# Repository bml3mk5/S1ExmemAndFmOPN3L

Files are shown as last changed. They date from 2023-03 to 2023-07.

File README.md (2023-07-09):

# Extended RAM & FM Synthesis Card for HITACHI MB-S1 (OPN3-L (YMF288) Version)

This is the extension card for HITACHI MB-S1 and Limelight. This is assembled two circuits
which are extended RAMs and FM Synthesis (YAMAHA YMF288(OPN3-L)). You can use two circuits, or just one of them.

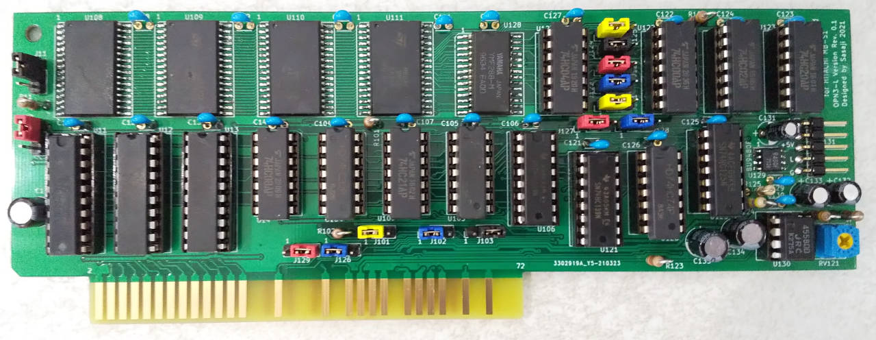
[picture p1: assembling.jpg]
Example of an assembling


## Used Tools

* KiCAD Version 5

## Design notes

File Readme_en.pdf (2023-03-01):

## Extended RAM & FM Synthesis Card for HITACHI MB-S1

## OPN3-L (YMF288) Version

Designed by Sasaji 2021 Rev. 0.1 This is the extension card for HITACHI MB-S1 and Limelight. This is assembled two circuits which are extended RAMs and FM Synthesis. You can use two circuits, or just one of them.

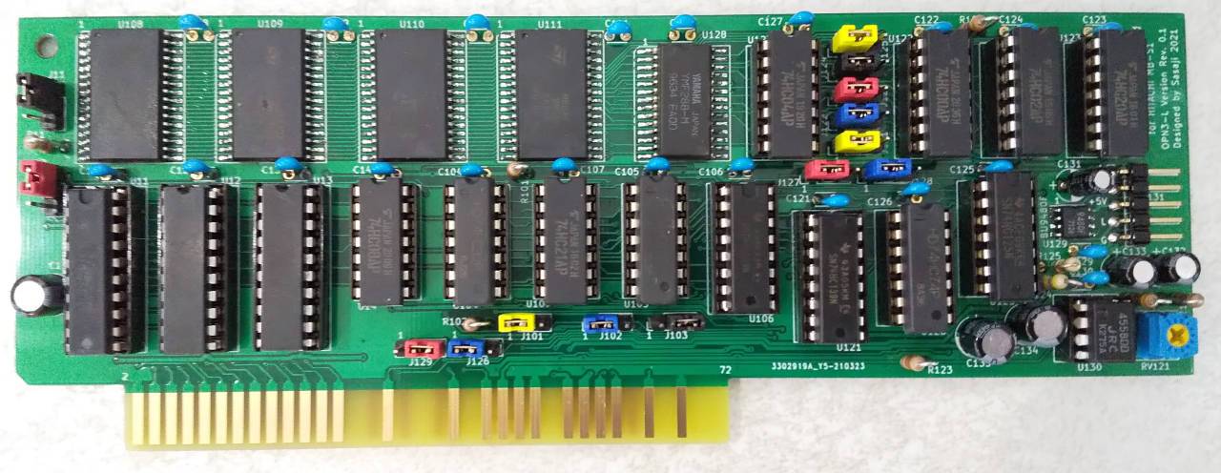
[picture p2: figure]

Example of assembling parts

## Parts List

- Parts number #1 to #99 are mandatory.
- Parts number #100 to #119 are necessary if you use extended RAMs.
- Parts number #120 to #139 are necessary if you use FM Synth.
Parts Number | Parts Name | Qty. | Description
C1 | Electrolytic Capacitor | 1 | 47～100uF, 16V～
C11~C130 | Ceramic Capacitor | 22 | 0.1uF
C131 | Electrolytic Capacitor | 1 | 10uF, 16V～
C132,C133 | Electrolytic Capacitor | 2 | 22uF～47uF, 16V～
C134,C135 | Electrolytic Capacitor | 2 | 47uF～100uF, 25V～
R11~R102, R126 | Carbon Resistor | 6 | 4.7KΩ～10KΩ, 1/4W～ (Pullup Register)
R121,R122 | Carbon Resistor | 2 | 4.7KΩ, 1/4W～
R123 | Carbon Resistor | 1 | 1KΩ, 1/4W～
R124 | Carbon Resistor | 1 | 100KΩ～470KΩ, 1/4W～ (For Opamp. Register value is 10 * R125)
R125 | Carbon Resistor | 1 | 10KΩ～47KΩ, 1/4W～ (For Opamp. Register value is R124 / 10)

RV121 | Potentiometer | 1 | 10KΩ Ex: Tokyo Cosmos GF063P1B103 (Volume sound)
U11 | CMOS Logic IC | 1 | 74HC245, DIP20
U12, U13 | CMOS Logic IC | 2 | 74HC541, DIP20
U14 | CMOS Logic IC | 1 | 74HC08, DIP14
U104 | CMOS Logic IC | 1 | 74HC32, DIP14
U105,U122 | CMOS Logic IC | 2 | 74HC00, DIP14
U106,U121 | CMOS Logic IC | 2 | 74HC139, DIP16
U107 | CMOS Logic IC | 1 | 74HC21, DIP14
U108~U111 | SRAM | 4 | M68AF127B or Compatible SRAM, SOIC32
U123 | CMOS Logic IC | 1 | 74HC20, DIP14
U124 | CMOS Logic IC | 1 | 74HC02, DIP14
U125 | CMOS Logic IC | 1 | 74HC125, DIP14
U126 | CMOS Logic IC | 1 | 74HC74, DIP14
U127 | CMOS Logic IC | 1 | 74HC04, DIP14
U128 | FMSynth IC | 1 | YMF288-M, SOIC28
U129 | DAC | 1 | BU9480F, SOP8 (16bit DAC, I²S)
U129 | Opamp | 1 | 4580 or 4558 ±12V, DIP8 (NJM4580D, RC4580)
J11~J129 | Jumper | 14 | Pin Header 3pin x1 2.54mm pitch straight
| Jumper Pin | 14 | To short pin headers.
| IC Socket

Optional Parts
Parts Number | Parts Name | Qty. | Description
J131 | Jumper | 1 | Pin Header 5pin x1 2.54mm pitch L.angled (For output sound)

## About Output Sound Signals Pin

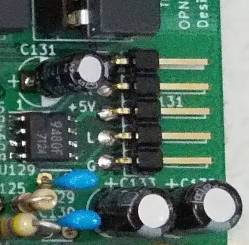
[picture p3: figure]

Pins are GND, Right OUT, +5V, Left OUT and GND from the top side. Sound is a direct signal from the DAC. If you use this signal, you must amplify it using an opamp.

## Setting Jumper

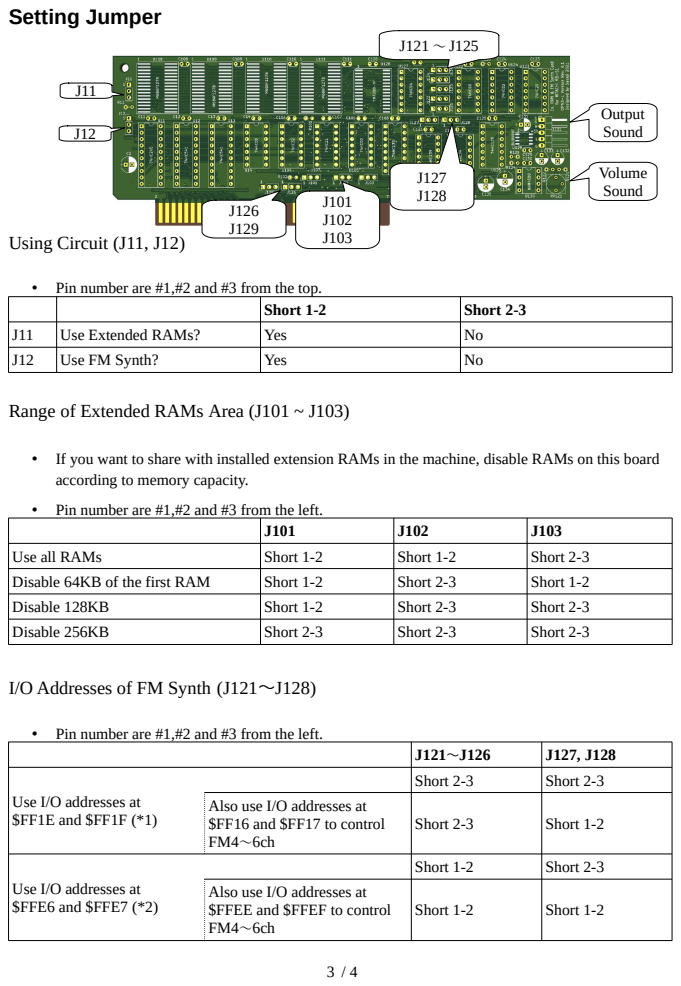
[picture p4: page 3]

• Pin number are #1,#2 and #3 from the top.

Short 1-2 | Short 2-3

J11 | Use Extended RAMs? | Yes | No
J12 | Use FM Synth? | Yes | No

Range of Extended RAMs Area (J101 ~ J103)

• If you want to share with installed extension RAMs in the machine, disable RAMs on this board
according to memory capacity.
• Pin number are #1,#2 and #3 from the left.

Use all RAMs | Short 1-2 | Short 1-2 | Short 2-3
Disable 64KB of the first RAM | Short 1-2 | Short 2-3 | Short 1-2
Disable 128KB | Short 1-2 | Short 2-3 | Short 2-3
Disable 256KB | Short 2-3 | Short 2-3 | Short 2-3

I/O Addresses of FM Synth (J121～J128)

Use I/O addresses at Also use I/O addresses at $FF1E and $FF1F (*1) $FF16 and $FF17 to control FM4～6ch | Short 2-3 | Short 2-3 Short 1-2

Use I/O addresses at Also use I/O addresses at $FFE6 and $FFE7 (*2) $FFEE and $FFEF to control FM4～6ch | Short 1-2 | Short 2-3 Short 1-2

(*1) Don’t use on B mode of MB-S1/30 and 40 because duplicate the FD interface. (*2) Select this if you use as Extended PSG.

Connecting Interrupt Signal of FM Synth (J129)

- Pin number are #1,#2 and #3 from the left.
| | Short 1-2 | Short 2-3
J129 | Connect to | IRQ | FIRQ

## Attention

- The jumpers J127 and J128 must be at the same shorting position.
- This board is a prototype. No consideration is given to noise generated during use and deterioration over time.

## Difference from OPN(YM2203)

- Added channel 4 to 6 of FM synth. Enable I/O addresses to use it (see Setting Jumper).
- Prescaler is constant (as FM:1/3, SSG:1/2 on OPN). This raises a pitch in the PLAY statement by one octave.
- The FM and SSG outputs are combined. It's not possible to adjust the volumes of each one individually.

## Disclaimer

I am not responsible for any damage caused by this board. You use this board at your own risk.

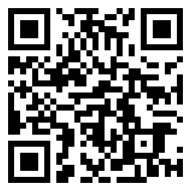
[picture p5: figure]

## Web

There are this document and a CAD data on the web. http://s-sasaji.ddo.jp/bml3mk5/s1exmemfm.htm
QR code →

Sasaji (sasaji@s-sasaji.ddo.jp) http://s-sasaji.ddo.jp/bml3mk5/(Twitter: https://twitter.com/bml3mk5)

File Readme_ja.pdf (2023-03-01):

# 拡張 RAM & FM 音源カード for 日立 MB-S1

# OPN3-L (YMF288) Version

### Designed by Sasaji 2021 Rev. 0.1

日立 MB-S1 および来夢来人用の拡張カードです。拡張 RAM の回路と FM 音源の回路を実装しています。 どちらか一方を使用するようにもできます。


実装例

## 部品表

- 1～99 番台の部品は必須です。
- 拡張 RAM を使用する場合、100～119 番台の部品が必要です。
- FM 音源を使用する場合、120～139 番台の部品が必要です。
番号 | 部品名 | 数量 | 値など
C1 | 電解コンデンサ | 1 | 47～100uF, 16V～
C11~C130 | セラミックコンデンサ | 22 | 0.1uF
C131 | 電解コンデンサ | 1 | 10uF, 16V～
C132,C133 | 電解コンデンサ | 2 | 22uF～47uF, 16V～
C134,C135 | 電解コンデンサ | 2 | 47uF～100uF, 25V～
R11~R102, R126 | カーボン抵抗 | 6 | 4.7KΩ～10KΩ, 1/4W～ （プルアップ抵抗）
R121,R122 | カーボン抵抗 | 2 | 4.7KΩ, 1/4W～
R123 | カーボン抵抗 | 1 | 1KΩ, 1/4W～
R124 | カーボン抵抗 | 1 | 100KΩ～470KΩ, 1/4W～ （オペアンプ用、抵抗値は R125 の 10 倍）
R125 | カーボン抵抗 | 1 | 10KΩ～47KΩ, 1/4W～ （オペアンプ用、抵抗値は R124 の 1/10）

RV121 | 半固定抵抗(ポテンショ メータ) | 1 | 10KΩ 東京コスモス電機 GF063P1B103 など （音量調整用）
U11 | CMOS ロジック IC | 1 | 74HC245, DIP20 ピン
U12, U13 | CMOS ロジック IC | 2 | 74HC541, DIP20 ピン
U14 | CMOS ロジック IC | 1 | 74HC08, DIP14 ピン
U104 | CMOS ロジック IC | 1 | 74HC32, DIP14 ピン
U105,U122 | CMOS ロジック IC | 2 | 74HC00, DIP14 ピン
U106,U121 | CMOS ロジック IC | 2 | 74HC139, DIP16 ピン
U107 | CMOS ロジック IC | 1 | 74HC21, DIP14 ピン
U108~U111 | SRAM | 4 | M68AF127B または互換 SRAM, SOIC32 ピン
U123 | CMOS ロジック IC | 1 | 74HC20, DIP14 ピン
U124 | CMOS ロジック IC | 1 | 74HC02, DIP14 ピン
U125 | CMOS ロジック IC | 1 | 74HC125, DIP14 ピン
U126 | CMOS ロジック IC | 1 | 74HC74, DIP14 ピン
U127 | CMOS ロジック IC | 1 | 74HC04, DIP14 ピン
U128 | FM 音源 IC | 1 | YMF288-M, SOIC28 ピン
U129 | DAC | 1 | BU9480F, SOP8 ピン （16 ビット DAC, I²S 入力のもの）
U129 | オペアンプ | 1 | 4580 や 4558 など±12V 以上のもの, DIP8 ピン （NJM4580D, RC4580 など）
J11~J129 | ジャンパ | 14 | ピンヘッダ 3 ピン x1 列 2.54mm ピッチ ストレート
| ジャンパピン | 14 | 上記ピンヘッダをショートさせるため
| IC ソケット

以下の部品はオプション

番号 | 部品名 | 数量 | 値など
J131 | ジャンパ | 1 | ピンヘッダ 5 ピン x1 列 2.54mm ピッチ L アングル （音声出力用）

## 音声出力端子について


### 上から、GND, Right OUT, +5V, Left OUT, GND となります。

音声は DAC からでた直後の信号です。ここから音声を取り出す場合は、オペア ンプなどで増幅してください。

## ジャンパピンの設定

J11

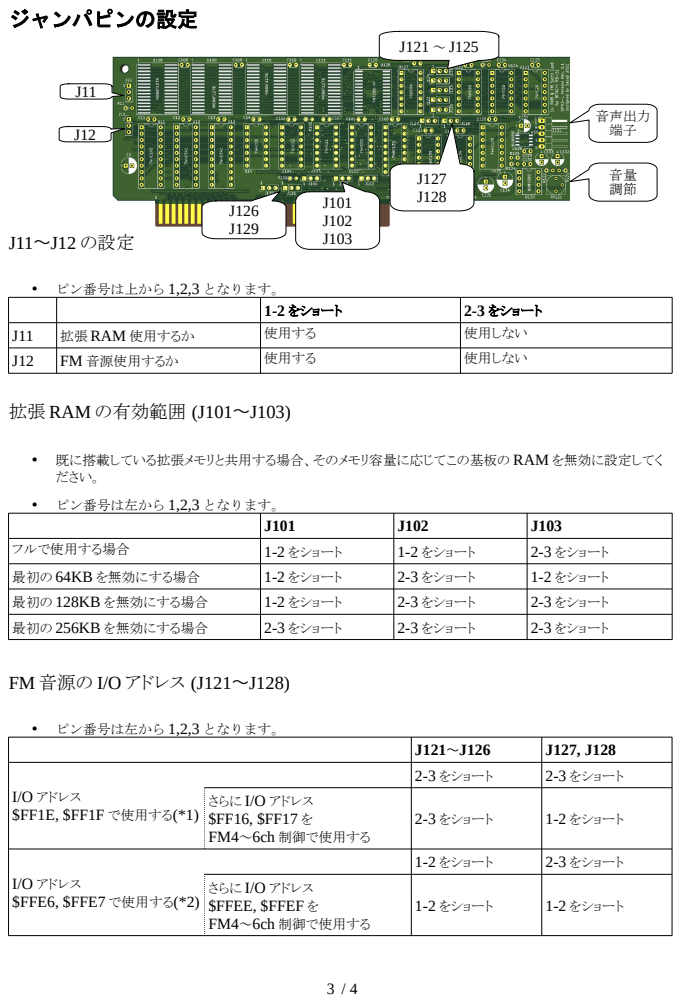
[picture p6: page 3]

1-2 をショート | 2-3 をショート

J11 | 拡張 RAM 使用するか | 使用する | 使用しない
J12 | FM 音源使用するか | 使用する | 使用しない

• 既に搭載している拡張メモリと共用する場合、そのメモリ容量に応じてこの基板の RAM を無効に設定してく
ださい。
• ピン番号は左から 1,2,3 となります。

フルで使用する場合 | 1-2 をショート | 1-2 をショート | 2-3 をショート
最初の 64KB を無効にする場合 | 1-2 をショート | 2-3 をショート | 1-2 をショート
最初の 128KB を無効にする場合 | 1-2 をショート | 2-3 をショート | 2-3 をショート
最初の 256KB を無効にする場合 | 2-3 をショート | 2-3 をショート | 2-3 をショート

I/O アドレス さらに I/O アドレス $FF1E, $FF1F で使用する(*1) $FF16, $FF17 を FM4～6ch 制御で使用する | 2-3 をショート | 2-3 をショート 1-2 をショート

I/O アドレス さらに I/O アドレス $FFE6, $FFE7 で使用する(*2) $FFEE, $FFEF を FM4～6ch 制御で使用する | 1-2 をショート | 2-3 をショート 1-2 をショート

(*1)FD インターフェースと重複するため、MB-S1/30,40 の B モードでは使用しないでください。 (*2)拡張 PSG として使用する場合はこちらを選択してください。

## FM 音源の割り込み信号接続先(J129)

- ピン番号は左から 1,2,3 となります。
| | 1-2 をショート | 2-3 をショート
J129 | 割り込み信号接続先 | IRQ | FIRQ

## 使用上の注意

- ジャンパ J127,J128 はショートする位置を合わせてください。
- この基板は試作品です。使用中に発生するノイズや経年劣化などに対しての考慮は全くしていません ので予めご了承ください。

# OPN(YM2203)との違い

- FM 音源部のチャンネル 4 から 6 が追加されました。これを使用するには FM4～6ch 制御で使用する I/O アドレスを有効にしてください(ジャンパピンの設定を参照)。
- 分周比が固定(OPN の設定 FM:1/3 SSG:1/2 に相当)になりました。このため PLAY 文での音程が 1 オクターブ上がります。
- FM 音源部と SSG 部が合成して出力されるようになりました。FM 音源と SSG 個別に音量を調整す ることはできません。

## 免責事項

この基板によって発生したいかなる損害についても当方は一切責任を負いません。 この基板を使用するにあたってはすべて自己責任で行ってください。


# Web ページ

この資料や CAD データなどを置いています。

### http://s-sasaji.ddo.jp/bml3mk5/s1exmemfm.htm

QR コード→

連絡先：

### Sasaji (sasaji@s-sasaji.ddo.jp) http://s-sasaji.ddo.jp/bml3mk5/ (Twitter: https://twitter.com/bml3mk5)

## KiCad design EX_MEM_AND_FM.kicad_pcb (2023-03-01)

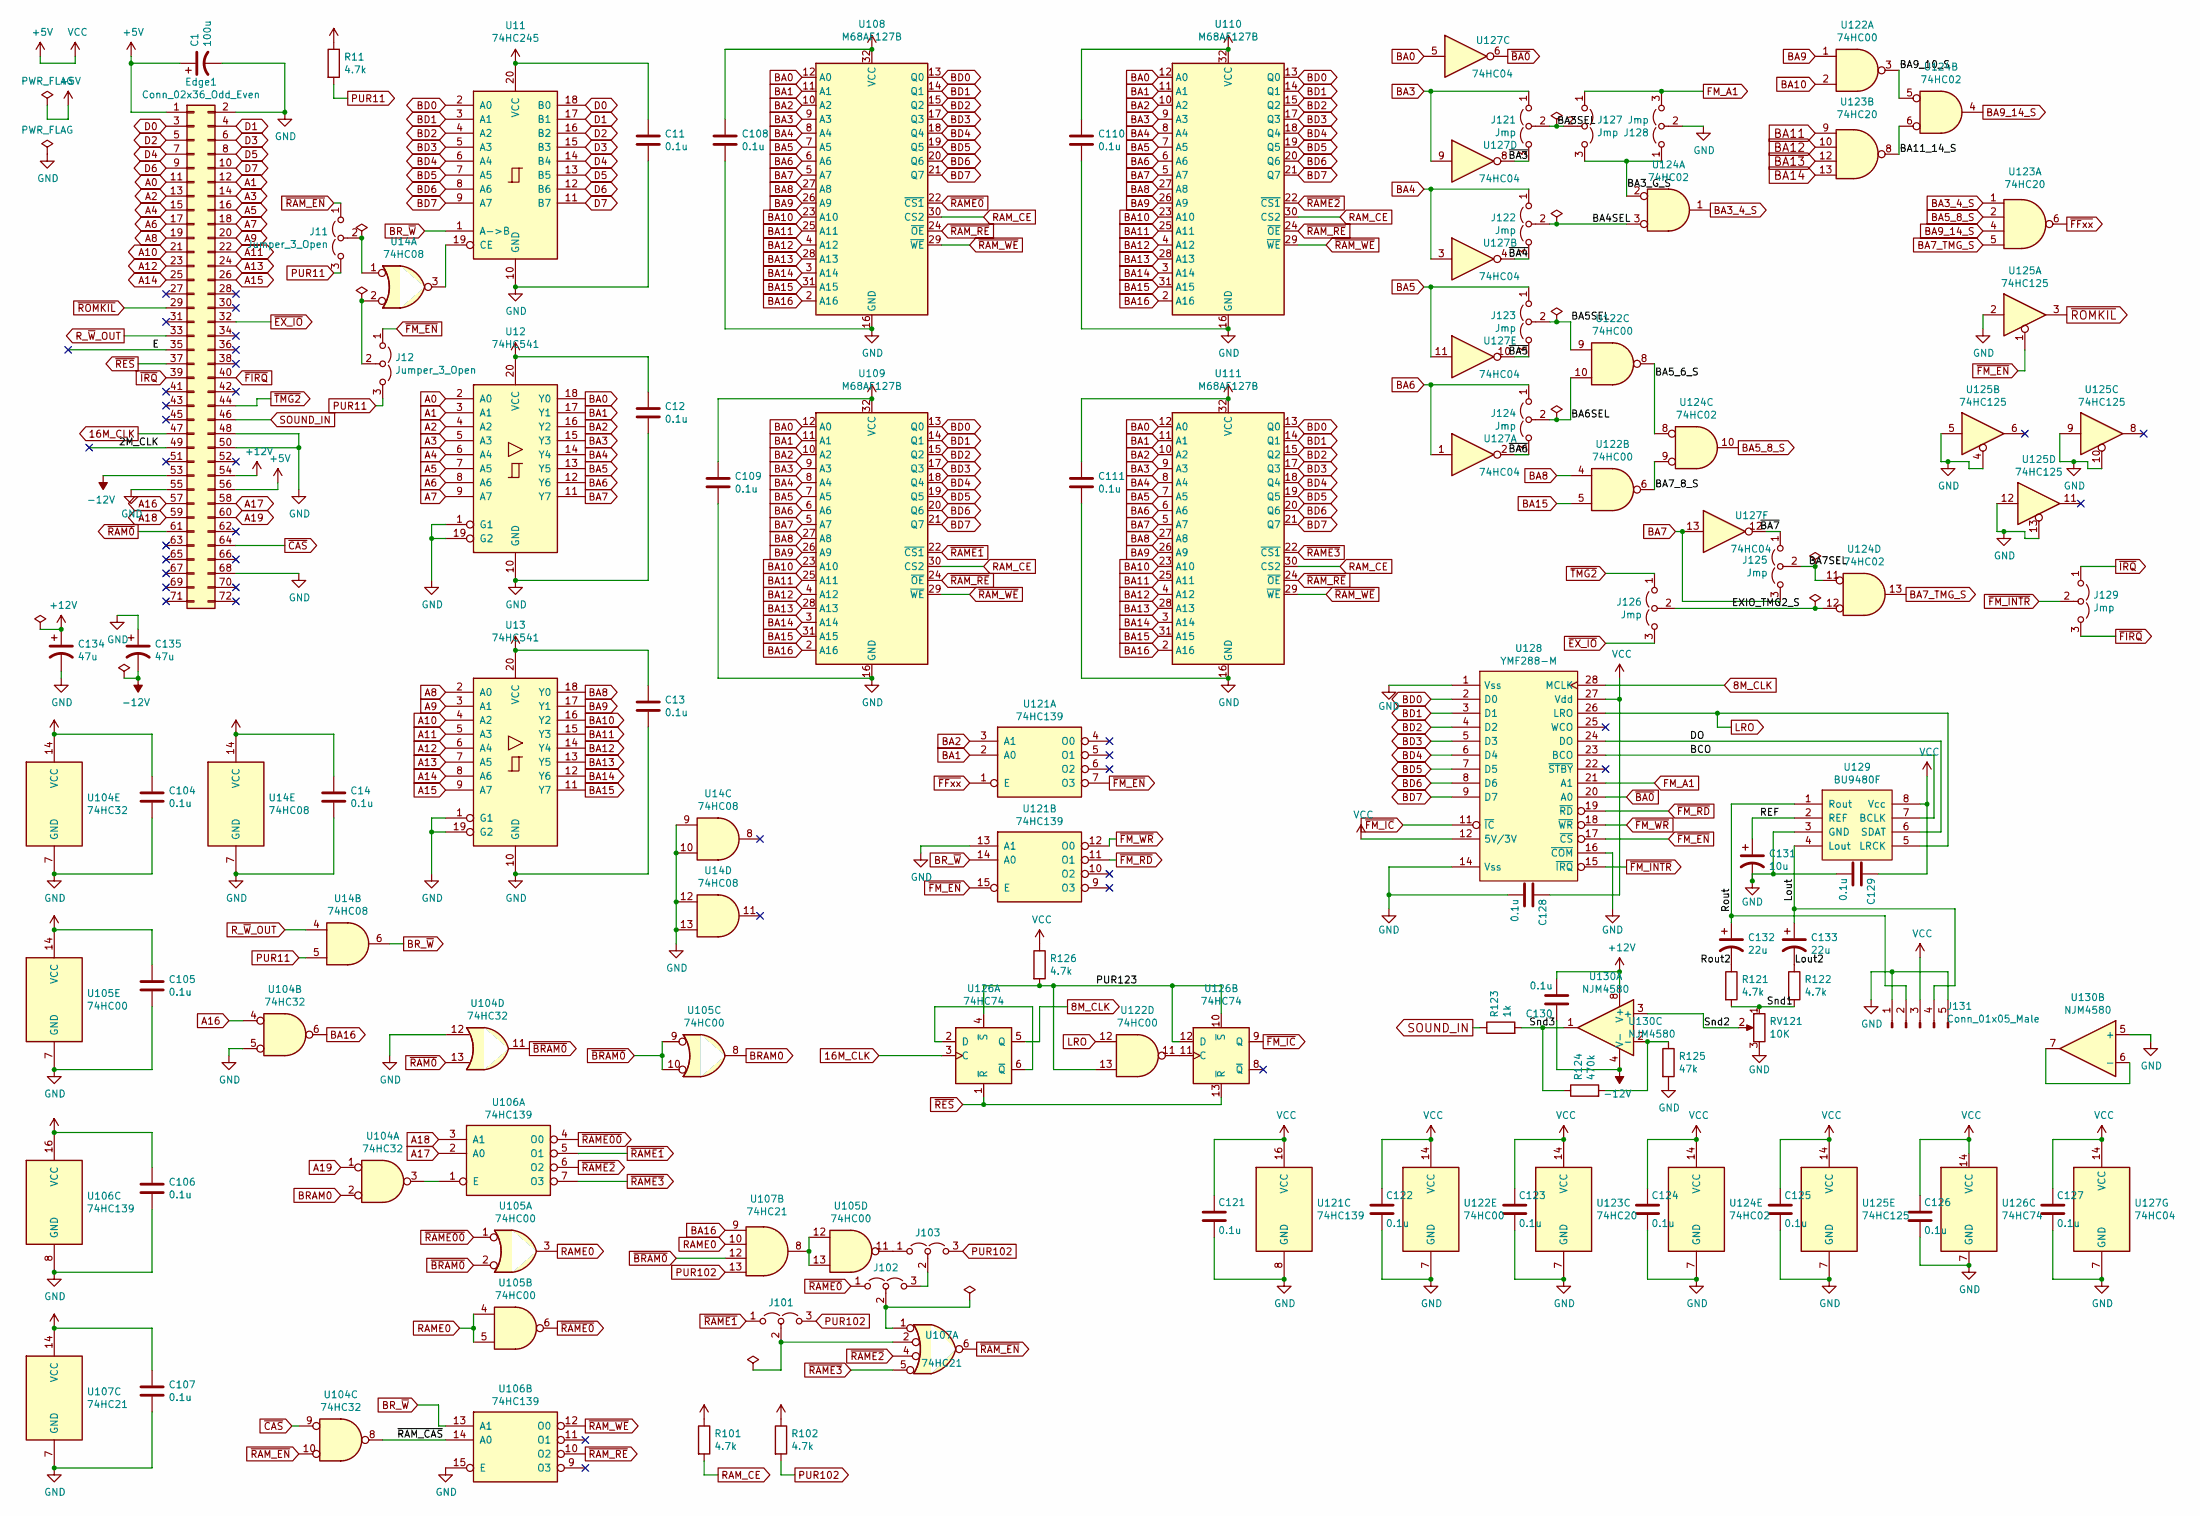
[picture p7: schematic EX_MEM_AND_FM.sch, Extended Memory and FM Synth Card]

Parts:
C1: 100u; CP_Radial_D6.3mm_P2.50mm
C11, C12, C13, C14, C104, C105, C106, C107, C108, C109, C110, C111, C121, C122, C123, C124, C125, C126, C127, C128, C129, C130: 0.1u; C_Disc_D3.0mm_W2.0mm_P2.50mm
C131: 10u; CP_Radial_D5.0mm_P2.50mm
C132, C133: 22u; CP_Radial_D5.0mm_P2.50mm
C134, C135: 47u; CP_Radial_D6.3mm_P2.50mm
Edge1: Conn_02x36_Odd_Even; CardEdge72
J11, J12, J101, J102, J103: Jumper_3_Open; Pin_Header_Straight_1x03_Pitch2.54mm
J121, J122, J123, J124, J125, J126, J127, J128, J129: Jmp; Pin_Header_Straight_1x03_Pitch2.54mm
J131: Conn_01x05_Male; Pin_Header_Angled_1x05_Pitch2.54mm
R11, R101, R102, R121, R122, R126: 4.7k; R_Axial_DIN0204_L3.6mm_D1.6mm_P2.54mm_Vertical
R123: 1k; R_Axial_DIN0204_L3.6mm_D1.6mm_P2.54mm_Vertical
R124: 470k; R_Axial_DIN0204_L3.6mm_D1.6mm_P2.54mm_Vertical
R125: 47k; R_Axial_DIN0204_L3.6mm_D1.6mm_P2.54mm_Vertical
RV121: 10K; Potentiometer_Trimmer_Bourns_3339P_Horizontal
U11: 74HC245; DIP-20_W7.62mm
U12, U13: 74HC541; DIP-20_W7.62mm
U14: 74HC08; DIP-14_W7.62mm
U104: 74HC32; DIP-14_W7.62mm
U105: 74HC00; DIP-14_W7.62mm
U106: 74HC139; DIP-16_W7.62mm
U107: 74HC21; DIP-14_W7.62mm
U108, U109, U110, U111: M68AF127B; SOIC-32
U121: 74HC139; DIP-16_W7.62mm_Socket
U122: 74HC00; DIP-14_W7.62mm_Socket
U123: 74HC20; DIP-14_W7.62mm_Socket
U124: 74HC02; DIP-14_W7.62mm_Socket
U125: 74HC125; DIP-14_W7.62mm_Socket
U126: 74HC74; DIP-14_W7.62mm_Socket
U127: 74HC04; DIP-14_W7.62mm
U128: YMF288-M; SOIC-28
U129: BU9480F; SOIC-8_3.9x4.9mm_Pitch1.27mm
U130: NJM4580; DIP-8_W7.62mm_Socket

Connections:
8M_CLK: U126.5 (Q), U128.28 (MCLK)
16M_CLK: Edge1.47, U126.3 (C)
+5V: C1.1, C11.1, C12.1, C13.1, C14.1, C104.1, C105.1, C106.1, C107.1, C108.1, C109.1, C110.1, C111.1, C121.1, C122.1, C123.1, C124.1, C125.1, C126.1, C127.1, C128.1, C129.1, Edge1.1, Edge1.56, J131.3, R11.1, R101.1, R102.1, R126.1, U11.20 (VCC), U12.20 (VCC), U13.20 (VCC), U14.14 (VCC), U104.14 (VCC), U105.14 (VCC), U106.16 (VCC), U107.14 (VCC), U108.32 (VCC), U109.32 (VCC), U110.32 (VCC), U111.32 (VCC), U121.16 (VCC), U122.14 (VCC), U123.14 (VCC), U124.14 (VCC), U125.14 (VCC), U126.14 (VCC), U127.14 (VCC), U128.12 (5V/3V), U128.27 (Vdd), U129.8 (Vcc)
+12V: C130.2, C134.1, Edge1.54, U130.8 (V+)
-12V: C130.1, C135.2, Edge1.53, U130.4 (V-)
/BA3SEL: J121.2 (C), J127.2 (C)
/BA3_G_S: J127.3 (B), J128.1 (A), U124.2
/BA4SEL: J122.2 (C), U124.3
/BA5SEL: J123.2 (C), U122.9
/BA5_6_S: U122.8, U124.8
/BA6SEL: J124.2 (C), U122.10
/BA7SEL: J125.2 (C), U124.11
/BA7_8_S: U122.6, U124.9
/BA9_10_S: U122.3, U124.5
/BA11_14_S: U123.8, U124.6
/BCO: U128.23 (BCO), U129.7 (BCLK)
/DO: U128.24 (DO), U129.6 (SDAT)
/EXIO_TMG2_S: J126.2 (C), U124.12
/Lout: C133.1, J131.4, U129.4 (Lout)
/Lout2: C133.2, R122.1
/PUR123: R126.2, U122.13, U126.4 (~S), U126.10 (~S), U126.12 (D)
/REF: C131.1, U129.2 (REF)
/Rout: C132.1, J131.2, U129.1 (Rout)
/Rout2: C132.2, R121.1
/Snd1: R121.2, R122.2, RV121.1
/Snd2: RV121.2, U130.3 (+)
/Snd3: R123.2, R124.1, U130.1
/~BA3: J121.3 (B), U127.8
/~BA4: J122.3 (B), U127.4
/~BA5: J123.3 (B), U127.10
/~BA6: J124.3 (B), U127.2
/~BA7: J125.1 (A), U127.12
/~RAM_CAS: U104.8, U106.14 (A0)
A0: Edge1.11, U12.2 (A0)
A1: Edge1.12, U12.3 (A1)
A2: Edge1.13, U12.4 (A2)
A3: Edge1.14, U12.5 (A3)
A4: Edge1.15, U12.6 (A4)
A5: Edge1.16, U12.7 (A5)
A6: Edge1.17, U12.8 (A6)
A7: Edge1.18, U12.9 (A7)
A8: Edge1.19, U13.2 (A0)
A9: Edge1.20, U13.3 (A1)
A10: Edge1.21, U13.4 (A2)
A11: Edge1.22, U13.5 (A3)
A12: Edge1.23, U13.6 (A4)
A13: Edge1.24, U13.7 (A5)
A14: Edge1.25, U13.8 (A6)
A15: Edge1.26, U13.9 (A7)
A16: Edge1.57, U104.4
A17: Edge1.58, U106.2 (A0)
A18: Edge1.59, U106.3 (A1)
A19: Edge1.60, U104.1
BA0: U12.18 (Y0), U108.12 (A0), U109.12 (A0), U110.12 (A0), U111.12 (A0), U127.5
BA1: U12.17 (Y1), U108.11 (A1), U109.11 (A1), U110.11 (A1), U111.11 (A1), U121.2 (A0)
BA2: U12.16 (Y2), U108.10 (A2), U109.10 (A2), U110.10 (A2), U111.10 (A2), U121.3 (A1)
BA3: J121.1 (A), U12.15 (Y3), U108.9 (A3), U109.9 (A3), U110.9 (A3), U111.9 (A3), U127.9
BA3_4_S: U123.1, U124.1
BA4: J122.1 (A), U12.14 (Y4), U108.8 (A4), U109.8 (A4), U110.8 (A4), U111.8 (A4), U127.3
BA5: J123.1 (A), U12.13 (Y5), U108.7 (A5), U109.7 (A5), U110.7 (A5), U111.7 (A5), U127.11
BA5_8_S: U123.2, U124.10
BA6: J124.1 (A), U12.12 (Y6), U108.6 (A6), U109.6 (A6), U110.6 (A6), U111.6 (A6), U127.1
BA7: J125.3 (B), U12.11 (Y7), U108.5 (A7), U109.5 (A7), U110.5 (A7), U111.5 (A7), U127.13
BA7_TMG_S: U123.5, U124.13
BA8: U13.18 (Y0), U108.27 (A8), U109.27 (A8), U110.27 (A8), U111.27 (A8), U122.4
BA9: U13.17 (Y1), U108.26 (A9), U109.26 (A9), U110.26 (A9), U111.26 (A9), U122.1
BA9_14_S: U123.4, U124.4
BA10: U13.16 (Y2), U108.23 (A10), U109.23 (A10), U110.23 (A10), U111.23 (A10), U122.2
BA11: U13.15 (Y3), U108.25 (A11), U109.25 (A11), U110.25 (A11), U111.25 (A11), U123.9
BA12: U13.14 (Y4), U108.4 (A12), U109.4 (A12), U110.4 (A12), U111.4 (A12), U123.10
BA13: U13.13 (Y5), U108.28 (A13), U109.28 (A13), U110.28 (A13), U111.28 (A13), U123.12
BA14: U13.12 (Y6), U108.3 (A14), U109.3 (A14), U110.3 (A14), U111.3 (A14), U123.13
BA15: U13.11 (Y7), U108.31 (A15), U109.31 (A15), U110.31 (A15), U111.31 (A15), U122.5
BA16: U104.6, U107.9, U108.2 (A16), U109.2 (A16), U110.2 (A16), U111.2 (A16)
BD0: U11.2 (A0), U108.13 (Q0), U109.13 (Q0), U110.13 (Q0), U111.13 (Q0), U128.2 (D0)
BD1: U11.3 (A1), U108.14 (Q1), U109.14 (Q1), U110.14 (Q1), U111.14 (Q1), U128.3 (D1)
BD2: U11.4 (A2), U108.15 (Q2), U109.15 (Q2), U110.15 (Q2), U111.15 (Q2), U128.4 (D2)
BD3: U11.5 (A3), U108.17 (Q3), U109.17 (Q3), U110.17 (Q3), U111.17 (Q3), U128.5 (D3)
BD4: U11.6 (A4), U108.18 (Q4), U109.18 (Q4), U110.18 (Q4), U111.18 (Q4), U128.6 (D4)
BD5: U11.7 (A5), U108.19 (Q5), U109.19 (Q5), U110.19 (Q5), U111.19 (Q5), U128.7 (D5)
BD6: U11.8 (A6), U108.20 (Q6), U109.20 (Q6), U110.20 (Q6), U111.20 (Q6), U128.8 (D6)
BD7: U11.9 (A7), U108.21 (Q7), U109.21 (Q7), U110.21 (Q7), U111.21 (Q7), U128.9 (D7)
BRAM0: U104.2, U105.8
BR_~W: U11.1 (A->B), U14.6, U106.13 (A1), U121.14 (A0)
D0: Edge1.3, U11.18 (B0)
D1: Edge1.4, U11.17 (B1)
D2: Edge1.5, U11.16 (B2)
D3: Edge1.6, U11.15 (B3)
D4: Edge1.7, U11.14 (B4)
D5: Edge1.8, U11.13 (B5)
D6: Edge1.9, U11.12 (B6)
D7: Edge1.10, U11.11 (B7)
FM_A1: J127.1 (A), J128.3 (B), U128.21 (A1)
GND: C1.2, C11.2, C12.2, C13.2, C14.2, C104.2, C105.2, C106.2, C107.2, C108.2, C109.2, C110.2, C111.2, C121.2, C122.2, C123.2, C124.2, C125.2, C126.2, C127.2, C128.2, C129.2, C131.2, C134.2, C135.1, Edge1.2, Edge1.48, Edge1.50, Edge1.55, Edge1.68, J128.2 (C), J131.1, J131.5, R125.2, RV121.3, U11.10 (GND), U12.1 (G1), U12.10 (GND), U12.19 (G2), U13.1 (G1), U13.10 (GND), U13.19 (G2), U14.7 (GND), U14.9, U14.10, U14.12, U14.13, U104.5, U104.7 (GND), U104.12, U105.7 (GND), U106.8 (GND), U106.15 (E), U107.7 (GND), U108.16 (GND), U109.16 (GND), U110.16 (GND), U111.16 (GND), U121.8 (GND), U121.13 (A1), U122.7 (GND), U123.7 (GND), U124.7 (GND), U125.2, U125.4, U125.5, U125.7 (GND), U125.9, U125.10, U125.12, U125.13, U126.7 (GND), U127.7 (GND), U128.1 (Vss), U128.14 (Vss), U128.16 (~COM), U129.3 (GND), U130.5 (+)
LRO: U122.12, U128.26 (LRO), U129.5 (LRCK)
unnamed: J11.2 (C), U14.1
unnamed: J12.2 (C), U14.2
unnamed: J101.2 (C), U107.2
unnamed: J102.2 (C), U107.1
unnamed: J102.3 (B), J103.2 (C)
unnamed: J103.1 (A), U105.11
unnamed: R124.2, R125.1, U130.2 (-)
unnamed: U11.19 (CE), U14.3
unnamed: U104.3, U106.1 (E)
unnamed: U105.12, U105.13, U107.8
unnamed: U122.11, U126.11 (C)
unnamed: U126.2 (D), U126.6 (~Q)
unnamed: U130.6 (-), U130.7
PUR11: J11.3 (B), J12.3 (B), R11.2, U14.5
PUR102: J101.3 (B), J103.3 (B), R102.2, U107.13
RAME0: U105.3, U105.4, U105.5, U107.10
RAM_CE: R101.2, U108.30 (CS2), U109.30 (CS2), U110.30 (CS2), U111.30 (CS2)
R_~W~_OUT: Edge1.33, U14.4
SOUND_IN: Edge1.46, R123.1
~BA0: U127.6, U128.20 (A0)
~BRAM0: U104.11, U105.2, U105.9, U105.10, U107.12
~CAS: Edge1.64, U104.9
~EX_IO: Edge1.32, J126.3 (B)
~FFxx: U121.1 (E), U123.6
~FIRQ: Edge1.40, J129.3 (B)
~FM_EN: J12.1 (A), U121.7 (O3), U121.15 (E), U125.1, U128.17 (~CS)
~FM_IC: U126.9 (Q), U128.11 (~IC)
~FM_INTR: J129.2 (C), U128.15 (~IRQ)
~FM_RD: U121.11 (O1), U128.19 (~RD)
~FM_WR: U121.12 (O0), U128.18 (~WR)
~IRQ: Edge1.39, J129.1 (A)
~RAM0: Edge1.61, U104.13
~RAME00: U105.1, U106.4 (O0)
~RAME0: J102.1 (A), U105.6, U108.22 (~CS1)
~RAME1: J101.1 (A), U106.5 (O1), U109.22 (~CS1)
~RAME2: U106.6 (O2), U107.4, U110.22 (~CS1)
~RAME3: U106.7 (O3), U107.5, U111.22 (~CS1)
~RAM_EN: J11.1 (A), U104.10, U107.6
~RAM_RE: U106.10 (O2), U108.24 (~OE), U109.24 (~OE), U110.24 (~OE), U111.24 (~OE)
~RAM_WE: U106.12 (O0), U108.29 (~WE), U109.29 (~WE), U110.29 (~WE), U111.29 (~WE)
~RES: Edge1.37, U126.1 (~R), U126.13 (~R)
~ROMKIL: Edge1.29, U125.3
~TMG2: Edge1.44, J126.1 (A)

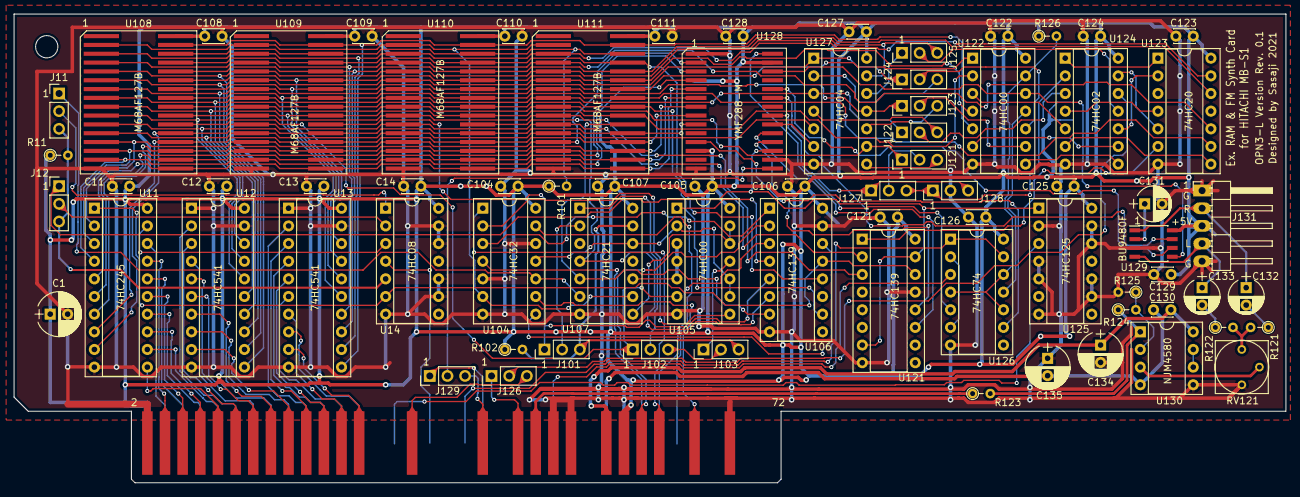
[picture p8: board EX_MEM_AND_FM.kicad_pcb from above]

Board: 2 copper layers, 183.0 x 67.4 mm, 76 parts (0 on the bottom side), 138 nets.
